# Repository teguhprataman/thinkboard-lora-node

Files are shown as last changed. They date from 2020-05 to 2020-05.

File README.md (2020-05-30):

# ThinkBoard LoRa Node V1

<p align="center">
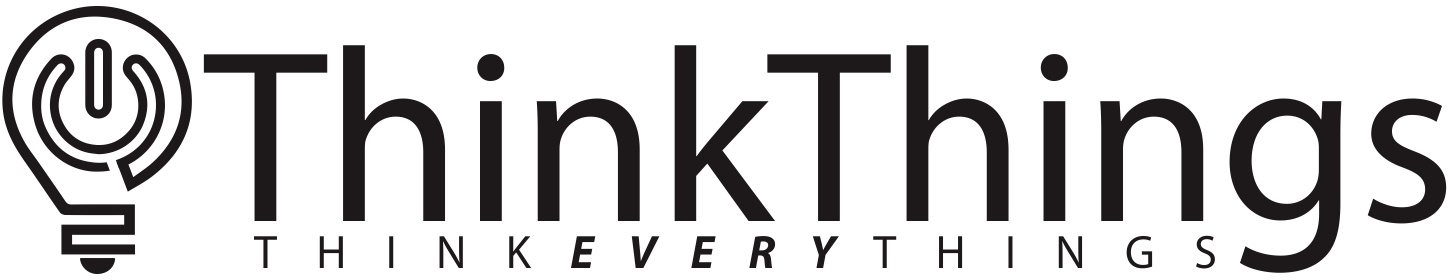
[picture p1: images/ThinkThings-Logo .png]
  
</p>

<br>

<p align="center">
  <br>
  <br>
  <b>Official Development Board For ThinkThings.id</b>
  <br> 
</p>

<p align="center"> 
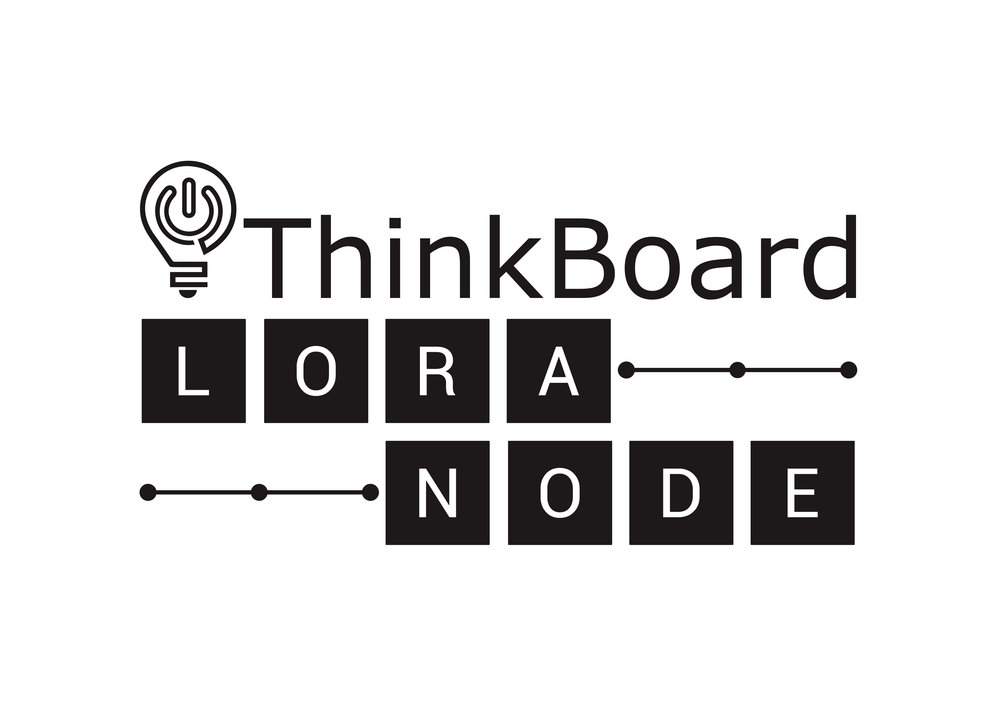
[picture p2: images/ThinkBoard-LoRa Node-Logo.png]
  
</p>

Daftar Isi
=================

<!--ts-->
   * [Daftar Isi](#daftar-isi)
   * [Deskripsi](#deskripsi)
   * [Spesifikasi](#spesifikasi)
   * [Pinout Diagram](#pinout-diagram)
   * [Bill Of Materials](#boms)
   * [Desain](#desain)
   * [Example](#example)
   * [Galeri](#galeri)
   * [Informasi](#informasi)
   * [Lisensi](#lisensi)
<!--te-->

## Deskripsi 
ThinkBoard LoRa Node V1 merupakan development board berbasis mikrokontroler ESP32 yang dilengkapi dengan modul radio HopeRF LoRa RFM95W 915MHz, sensor BME280 dan RGB LED WS2812 yang terintegrasi. Development board ini dirancang untuk mendukung segala kebutuhan pengguna dalam proyek Internet of Things, dengan tersedianya berbagai konektivitas seperti Bluetooth Low Energy, Wi-Fi, dan LoRa membuat development board ini sangat fleksibel untuk digunakan pada berbagai jaringan.

## Spesifikasi
**•	MCU :** ESP32 WROOM Dual – Core 4MB SPI Flash

**•	Dimensions :** 62mm x 38mm

**•	Headers :** 1x15 Pin & 1x17 Pin with 2.54mm pitch and castellated holes

**•	GPIO :** 26 pin GPIO @3V3 Logic Level: 2 x UART, 2 x SPI, 1 x I2C, 16 x 12 bits ADC, 2 x 8 bits DAC, 10 x Touch Capacitive, 16 x PWM Output Channels

**•	USB to UART :** Silicon Labs CP2104 USB – to – UART Bridge Controller

**•	Connectivity :** LoRa RFM95W 915MHz, Wi-Fi, Bluetooth

**•	Built-in Sensor :** BME280 digital humidity, pressure, and temperature sensor @0x76 address

**•	Built-in LED :** 3 x single color indicator LED, 1 x single color built-in LED attached to GPIO2, 1 x RGB LED WS2812 attached to GPIO33

**•	Power :** AP2112K 3.3V LDO 600mA regulator, USB or battery operated Vin : 6.5V max / 5V typ. / 4.2V min

**•	Battery Charger :** MCP73831 Single Cell Li-Ion, Li-Po battery charger

**•	Connector :** USB Micro B, U.FL antenna connector

## Pinout Diagram


***Catatan :** GPIO 34-39 hanya dapat digunakan sebagai input

## BOMs
No | Designator                        | Item/Value    | Footprint     | Quantity
-- | --------------------------------- | ------------- | ------------- | -------------
1  |  C1, C2, C4, C7, C8, C11, C12, C13| 1µF           | Ceramic 0603  | 8             |
2  |  C6                               | 4.7µF         | Ceramic 0603  | 1             |
3  |  C3, C5                           | 10µF          | Ceramic 0603  | 2             |
4  |  C9, C10                          | 4.7µF         | Ceramic 0805  | 2             |
5  |  C6                               | 4.7µF         | Ceramic 0603  | 1             |
6  |  R4, R5, R7, R8, R9, R10          | 10KΩ          |   1/16W 0603  | 6             |
7  |  R2                               | 100KΩ         |   1/16W 0603  | 1             |
8  |  R3                               | 4K7Ω          |   1/16W 0603  | 1             |
9  |  R6                               | 1KΩ           |2X4 ARRAY 0804 | 1             |
10 |  D1                               | 1N5822        |     DO214     | 1             |
11 |  D2                               | LED YELLOW    |     0603      | 1             |
12 |  D3                               | LED BLUE      |     0603      | 1             |
13 |  D4                               | LED GREEN     |     0603      | 1             |
14 |  D5                               | LED RED       |     0603      | 1             |
15 |  D2                               | LED YELLOW    |     0603      | 1             |
16 |  LED                              | WS2812B       |     5050      | 1             |
17 |  D2                               | LED YELLOW    |     0603      | 1             |
18 |  IC1                              | SI2301        |    SOT-23     | 1             |
19 |  IC2                              | AP2112K       |    SOT-25     | 1             |
20 |  IC3                              | MCP73831      |   SOT-23-5    | 1             |
21 |  U1                               | ESP32 WROOM   |   WROOM-32    | 1             |
22 |  U2                               | CP2104        |    QFN-24     | 1             |
23 |  U3                               | BME280        |  8 Pin - LGA  | 1             |
24 |  U4                               | RFM95W        |   8 x 2 Pin   | 1             |
25 |  Q1, Q2                           | MMBT3904      |    SOT-23     | 2             |
26 |  S1                               | Tactile Switch|     5 Pin     | 1             |
27 |  SW1                              | DIP Switch    |     2 Pin     | 1             |
28 |  SW1                              | DIP Switch    |     2 Pin     | 1             |
29 |  J1                               | PH Connector  |   2 Pin SMD   | 1             |
30 |  J2                               | USB Micro B   |      SMD      | 1             |
31 |  P1                               | Header 1x15   |  2.54mm Pitch | 1             |
32 |  P2                               | Header 1x17   |  2.54mm Pitch | 1             |
33 |                                   | U.FL Connector|      SMT      | 1             |

## Desain
ThinkBoard LoRa Node V1 merupakan hardware open-source yang di desain menggunakan software Altium Designer 20.1, namun terdapat juga file yang dapat dibuka menggunakan software freeware CircuitMaker.

Silakan gunakan design hardware ini dengan bijak.

File PCB Altium Designer, silakan lihat [Altium Designer](https://github.com/teguhprataman/thinkboard/tree/master/desain/Altium-Designer) 

File PCB CircuitMaker, silakan lihat [CircuitMaker](https://circuitmaker.com/Projects/Details/TeguhPratama/ThinkBoard-LoRa-Node-V1-CircuitMaker/embeded)

## Example

ThinkBoard LoRa Node V1 dapat diprogram menggunakan ArduinoIDE, dengan memilih ESP32 Dev Module pada bagian board di ArduinoIDE.

Lihat [example](https://github.com/teguhprataman/thinkboard/tree/master/example) untuk contoh program

Adapun library depedency untuk example diatas :

**• BME280** https://github.com/adafruit/Adafruit_BME280_Library

**• NeoPixel WS2812B** https://github.com/adafruit/Adafruit_NeoPixel

**• LoRa P2P** https://github.com/sandeepmistry/arduino-LoRa

**• LoRaWAN-Node** https://github.com/BeelanMX/Beelan-LoRaWAN

## Galeri
Lihat [galeri](https://github.com/teguhprataman/thinkboard/tree/master/images) untuk melihat gambar dari board ThinkBoard LoRa Node V1

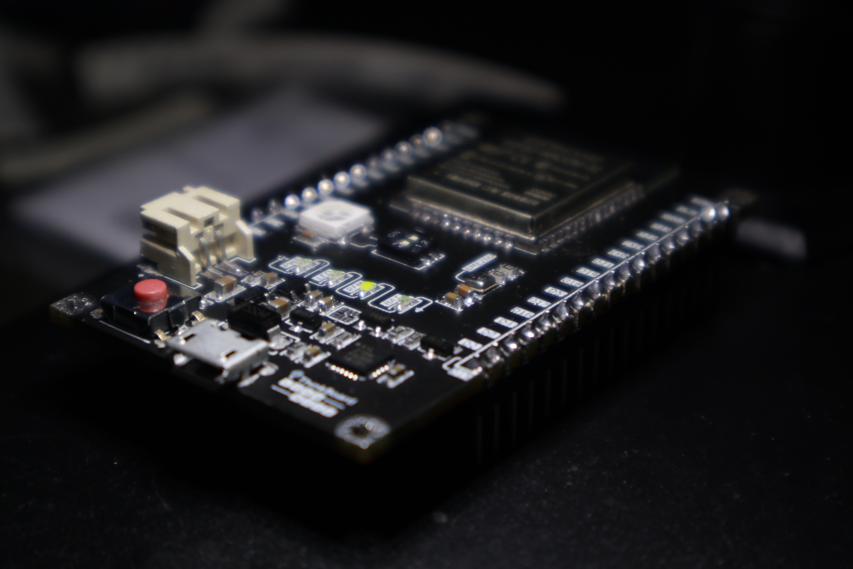
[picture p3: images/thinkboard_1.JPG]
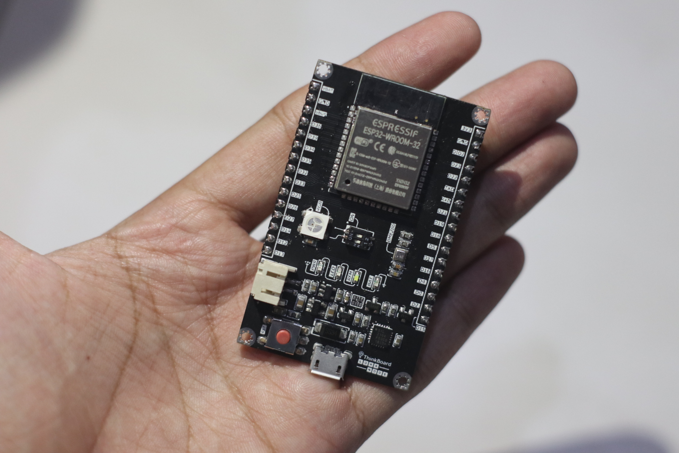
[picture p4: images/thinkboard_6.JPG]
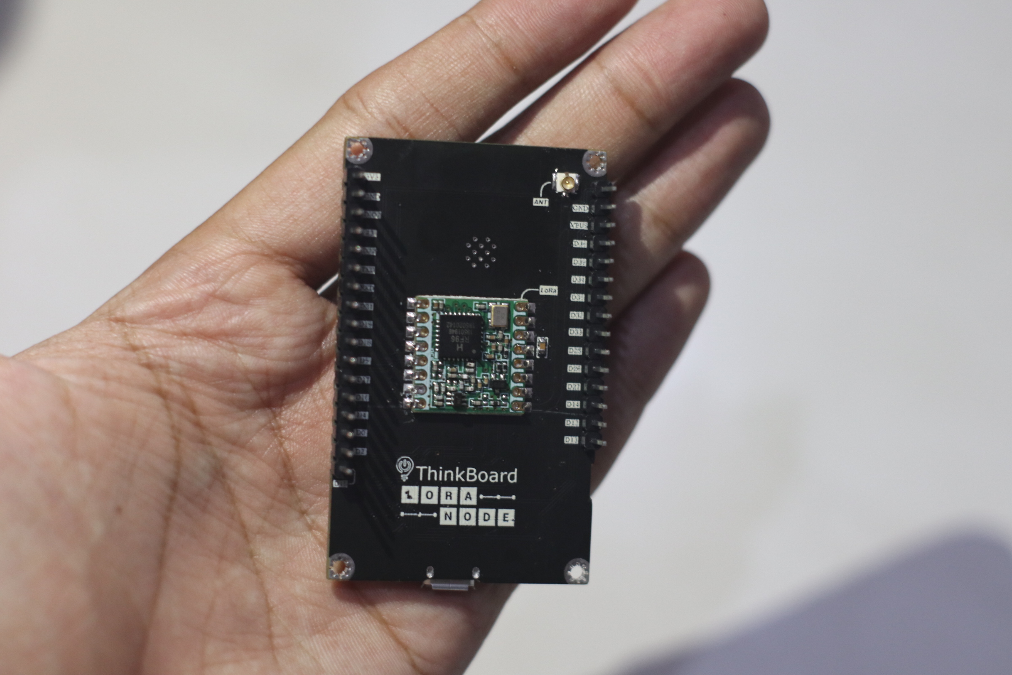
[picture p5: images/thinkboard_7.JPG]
   

## Informasi

Author : Teguh Pratama

E-mail : teguhvnkn@gmail.com

Website : thinkthings.id (offline)

## Lisensi
Desain hardware menggunakan lisensi  <a rel="license" href="http://creativecommons.org/licenses/by-nc-sa/4.0/">Creative Commons Attribution-NonCommercial-ShareAlike 4.0 International License</a>.

Software menggunakan lisensi <a rel="license" href="https://www.gnu.org/licenses/lgpl-3.0.txt">GNU Lesser General Public License Version 3</a>.

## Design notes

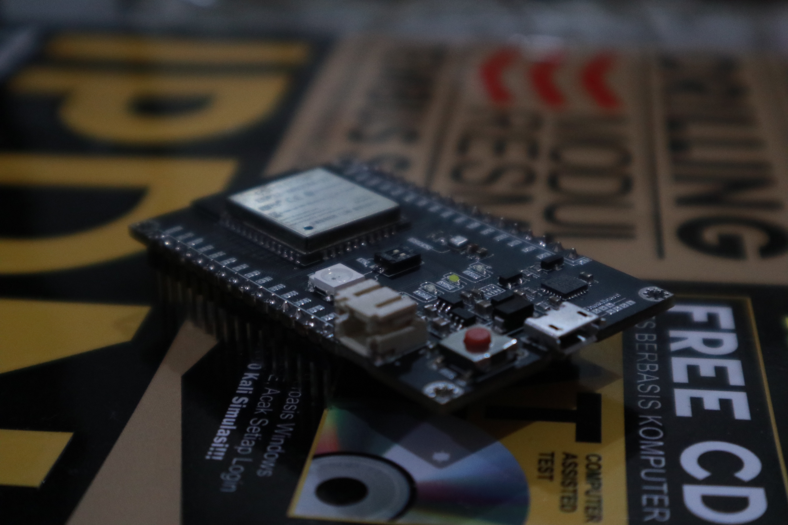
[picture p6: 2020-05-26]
images/thinkboard_2.JPG

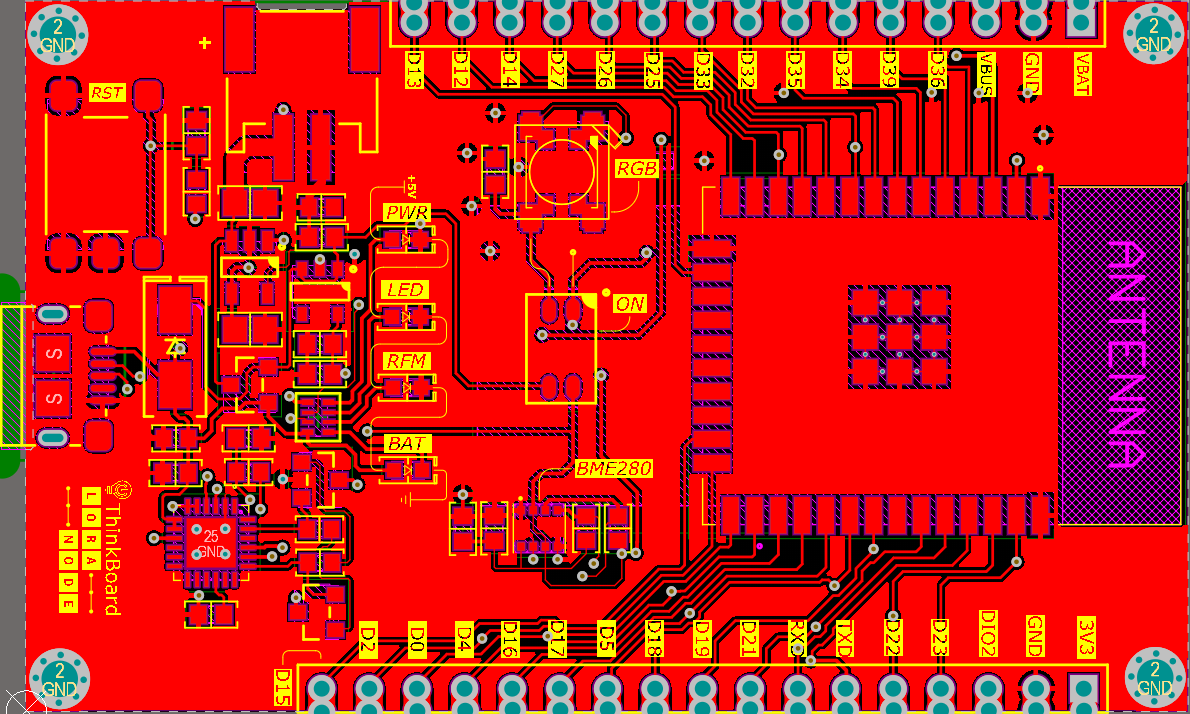
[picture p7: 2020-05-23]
images/top-layer.PNG

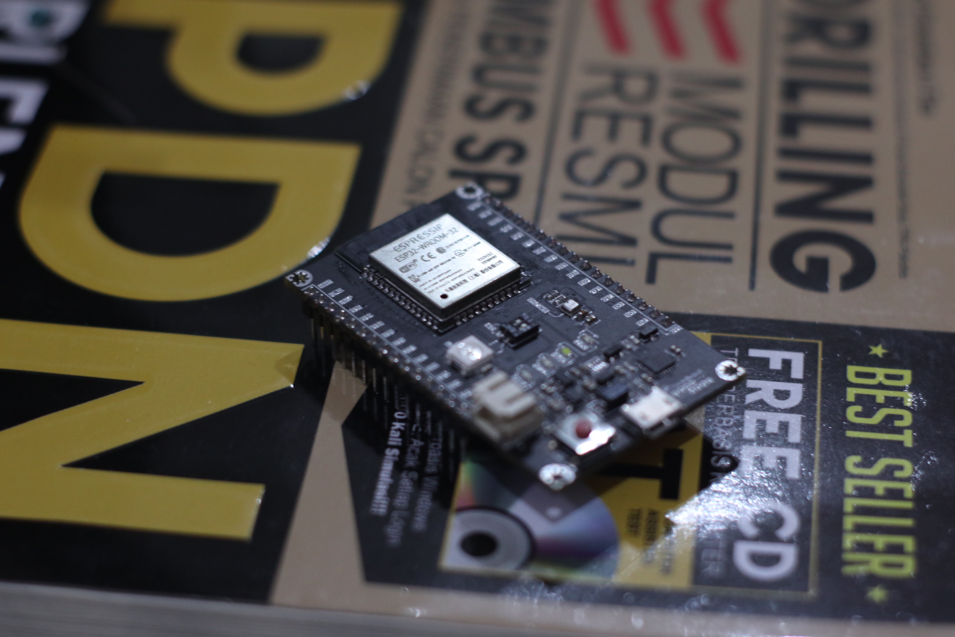
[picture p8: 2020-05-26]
images/thinkboard_3.JPG

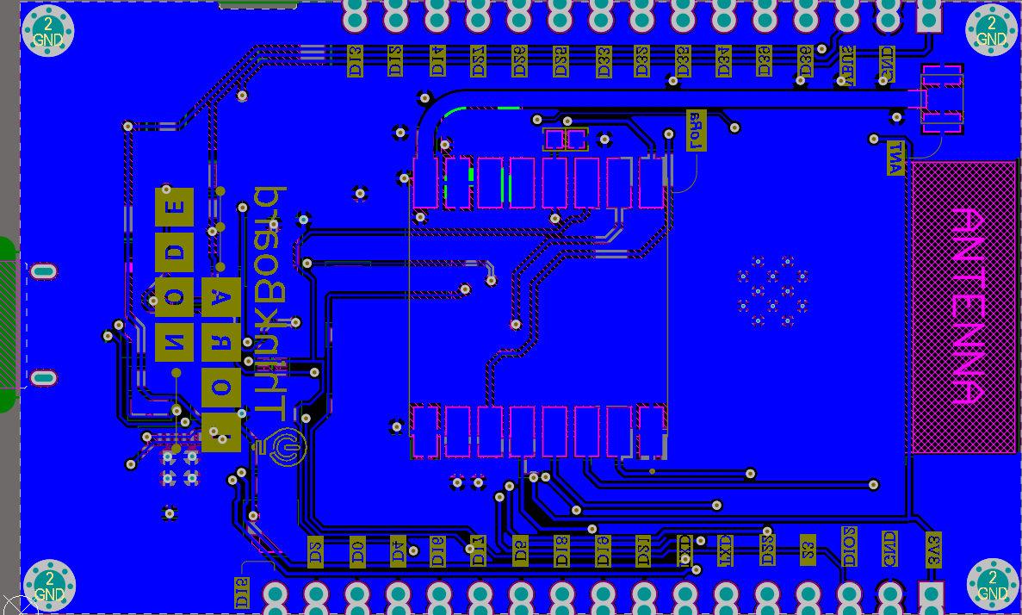
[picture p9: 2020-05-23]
images/bottom-layer.PNG

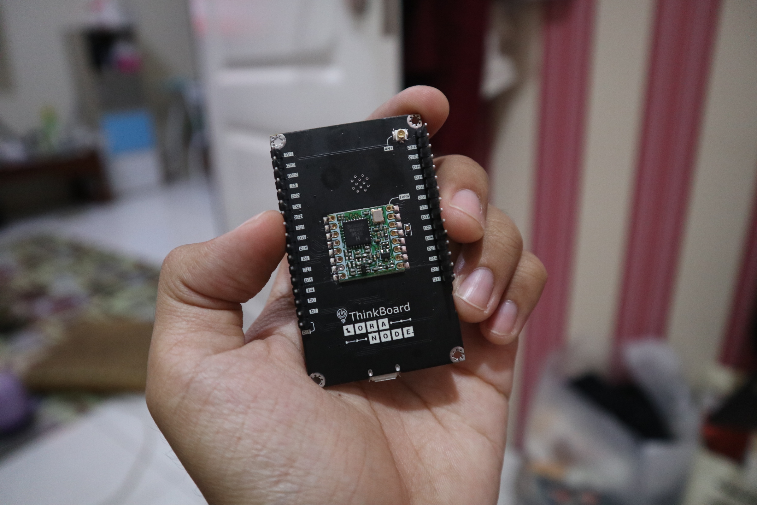
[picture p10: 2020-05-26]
images/thinkboard_4.JPG

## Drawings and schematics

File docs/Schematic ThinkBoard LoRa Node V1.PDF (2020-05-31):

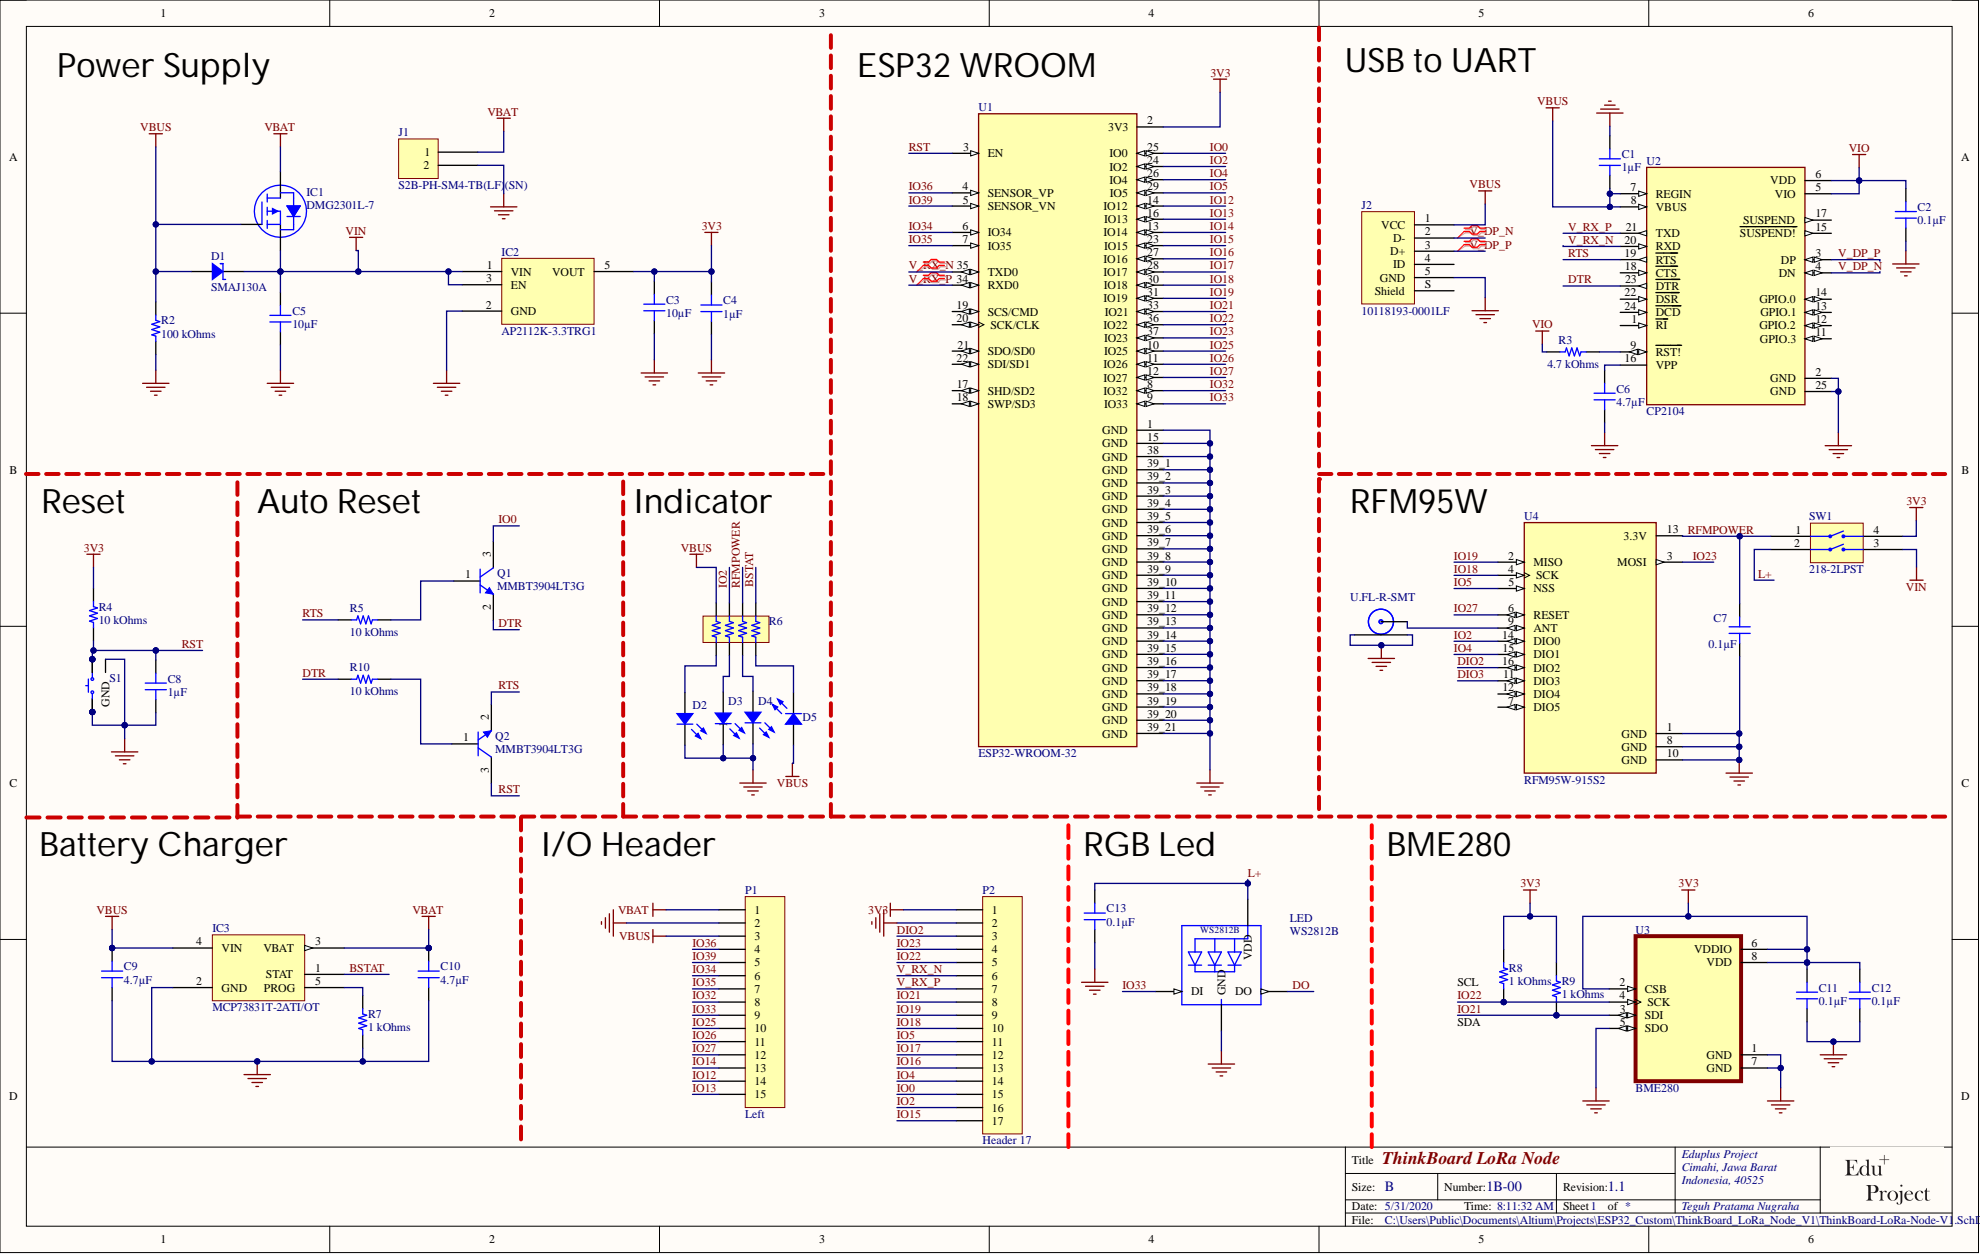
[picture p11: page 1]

C:\Users\Public\Documents\Altium\Projects\ESP32_Custom\ThinkBoard_LoRa_Node_V1\ThinkBoard-LoRa-Node-V1.SchDoc

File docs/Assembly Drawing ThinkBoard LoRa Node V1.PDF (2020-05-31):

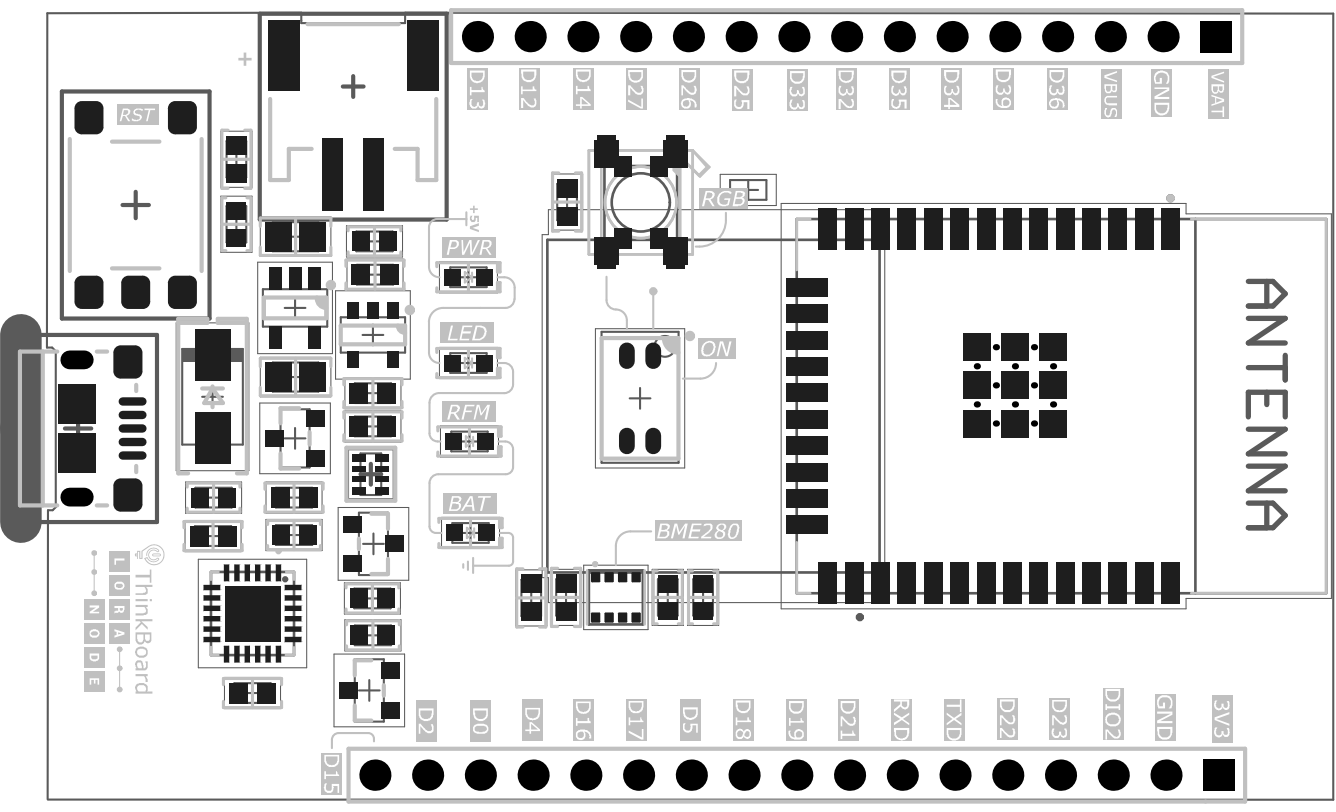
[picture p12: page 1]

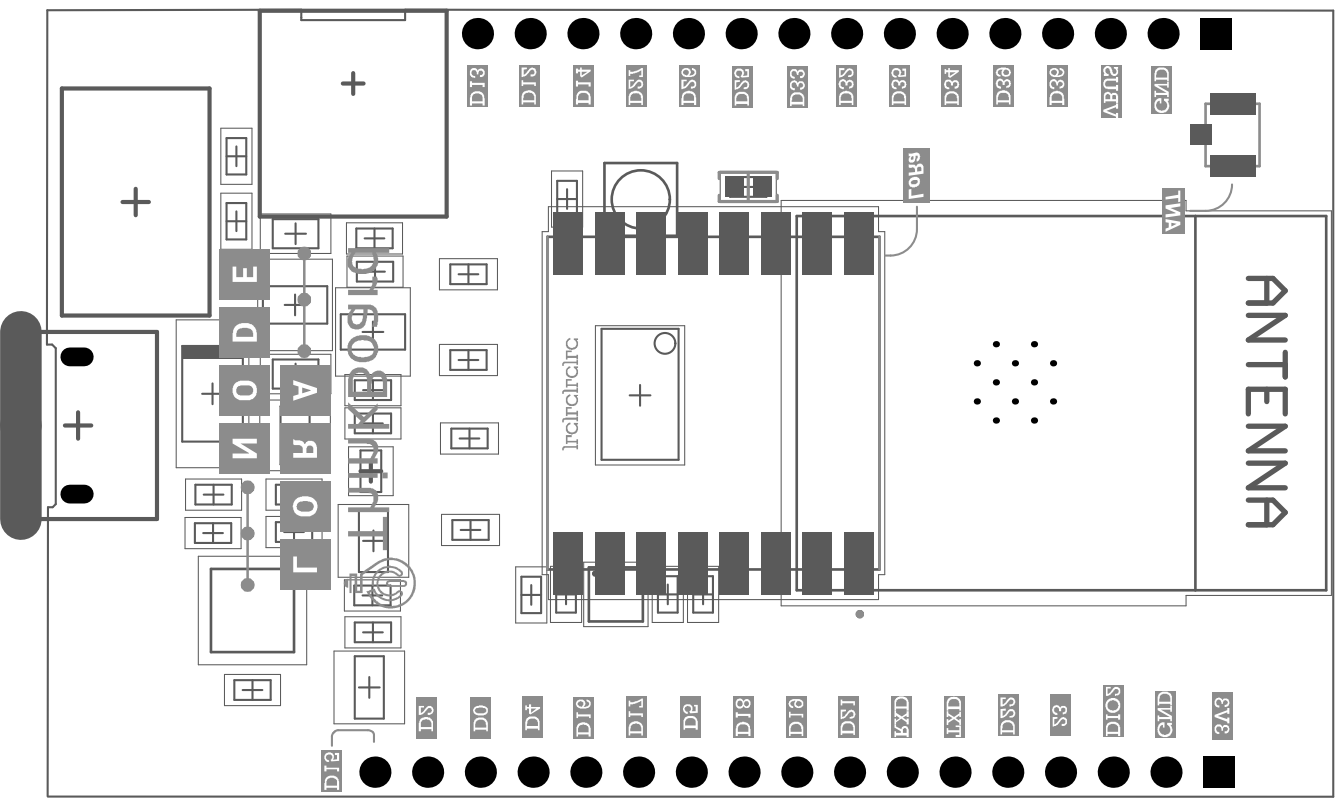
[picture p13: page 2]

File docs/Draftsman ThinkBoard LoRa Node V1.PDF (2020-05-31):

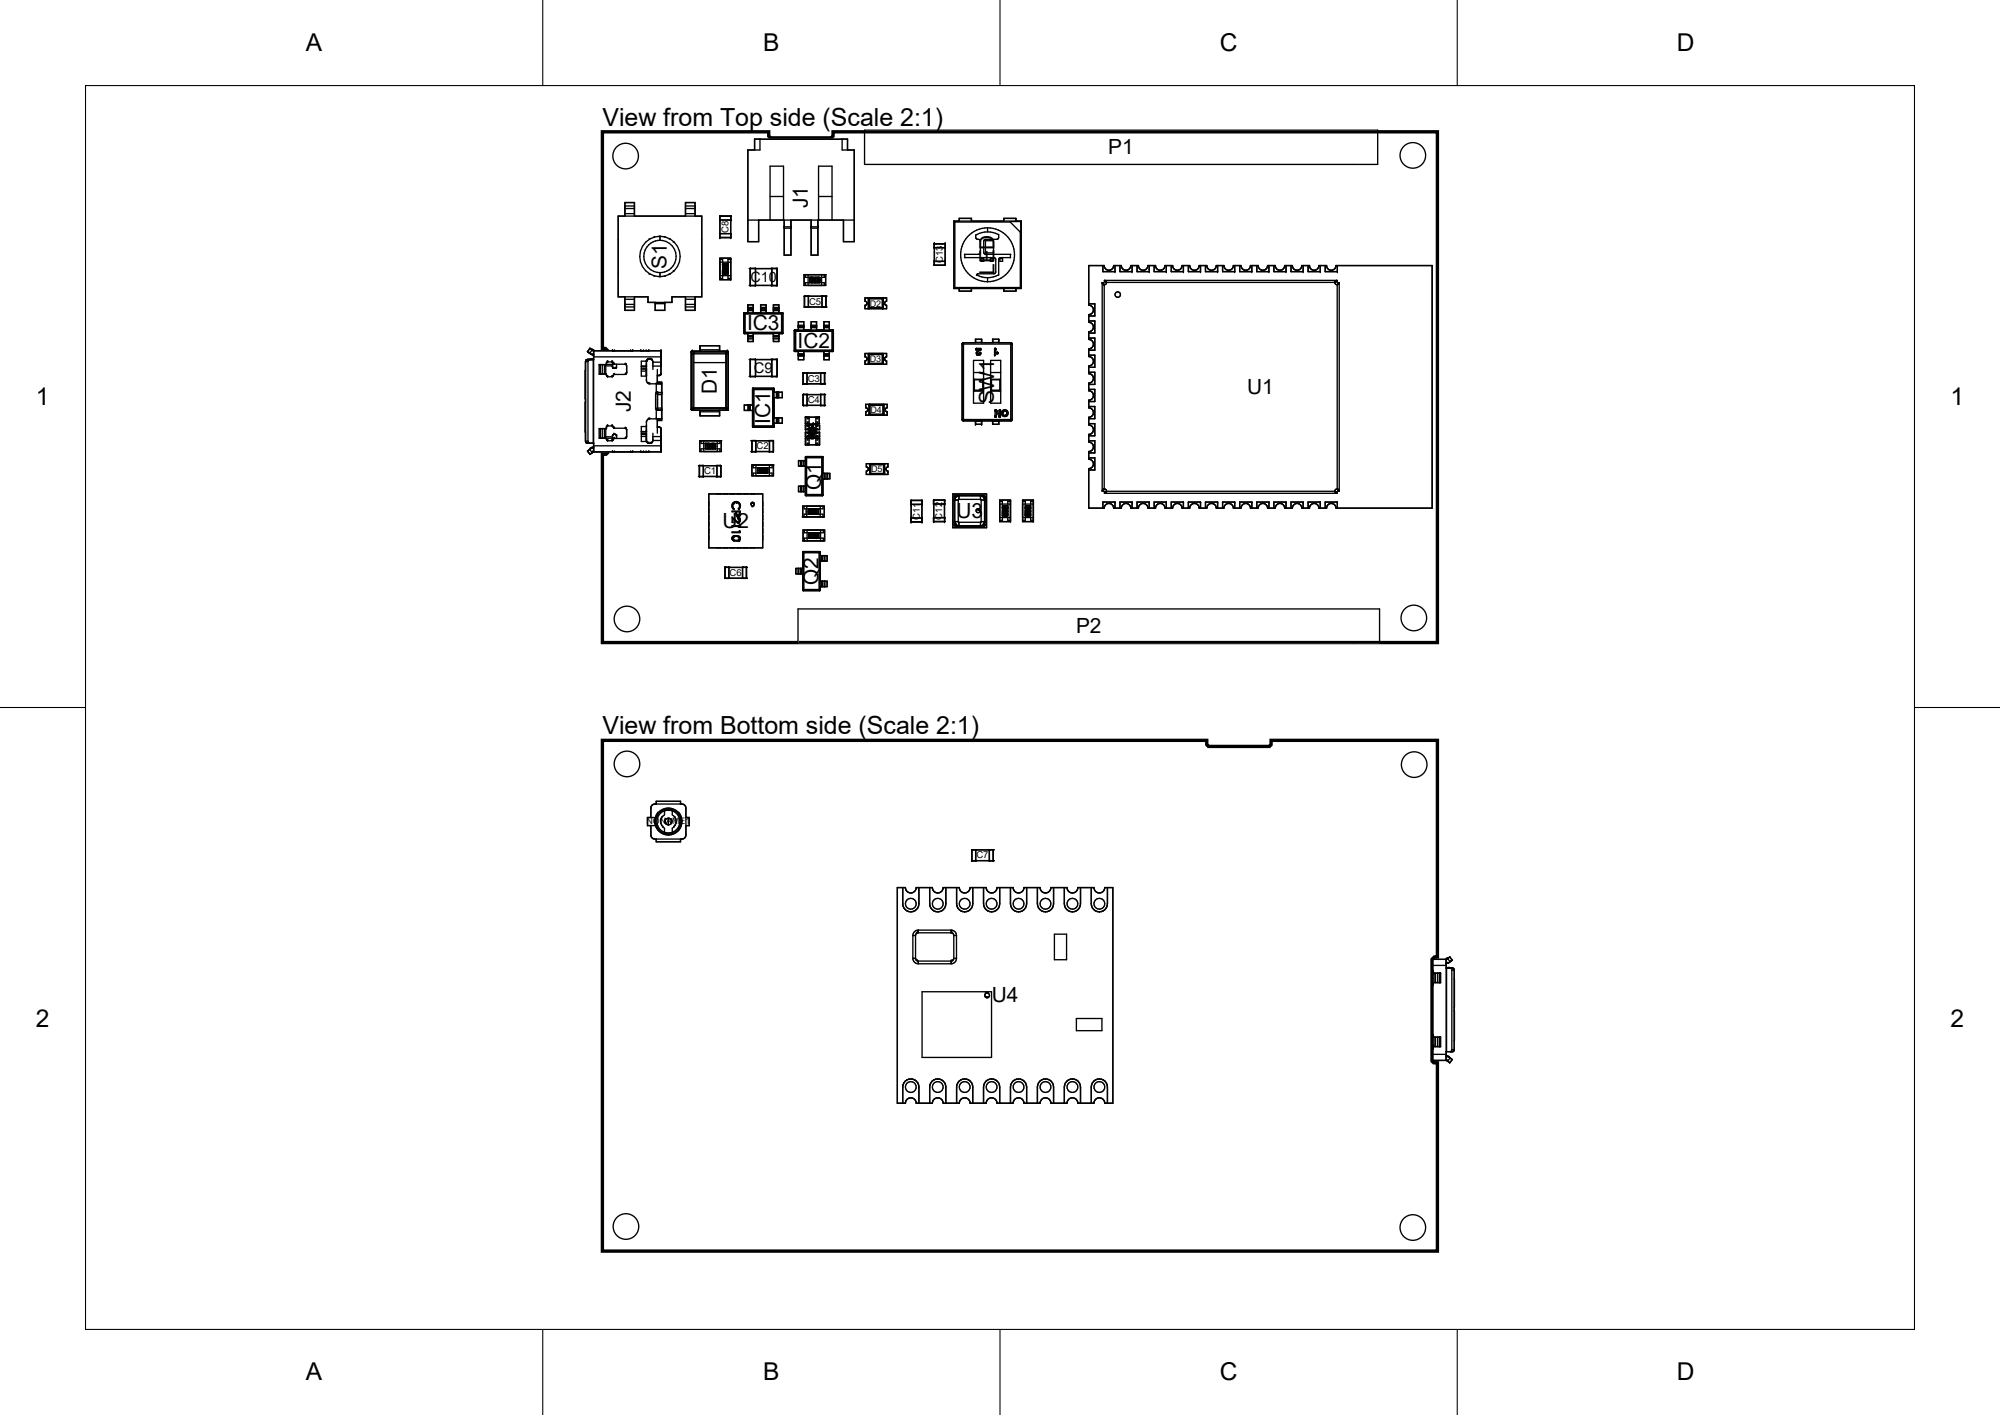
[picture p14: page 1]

View from Top side (Scale 2:1)

View from Bottom side (Scale 2:1)

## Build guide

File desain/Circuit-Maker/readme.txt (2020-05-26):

https://circuitmaker.com/Projects/Details/TeguhPratama/ThinkBoard-LoRa-Node-V1-CircuitMaker/embeded

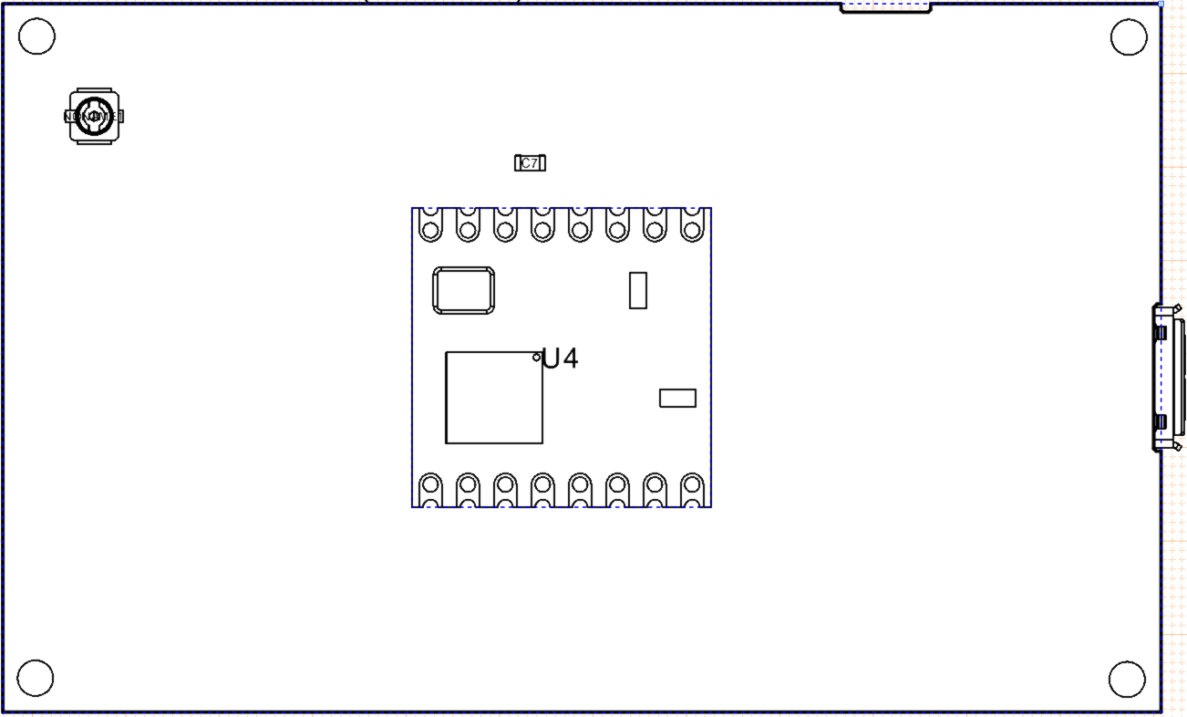
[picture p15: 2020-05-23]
images/board-assembly-bottom-layer.PNG

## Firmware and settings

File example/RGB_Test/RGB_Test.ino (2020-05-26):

// A basic everyday NeoPixel strip test program.

// NEOPIXEL BEST PRACTICES for most reliable operation:
// - Add 1000 uF CAPACITOR between NeoPixel strip's + and - connections.
// - MINIMIZE WIRING LENGTH between microcontroller board and first pixel.
// - NeoPixel strip's DATA-IN should pass through a 300-500 OHM RESISTOR.
// - AVOID connecting NeoPixels on a LIVE CIRCUIT. If you must, ALWAYS
//   connect GROUND (-) first, then +, then data.
// - When using a 3.3V microcontroller with a 5V-powered NeoPixel strip,
//   a LOGIC-LEVEL CONVERTER on the data line is STRONGLY RECOMMENDED.
// (Skipping these may work OK on your workbench but can fail in the field)

#include <Adafruit_NeoPixel.h>
#ifdef __AVR__
 #include <avr/power.h> // Required for 16 MHz Adafruit Trinket
#endif

// Which pin on the Arduino is connected to the NeoPixels?
// On a Trinket or Gemma we suggest changing this to 1:
#define LED_PIN    33

// How many NeoPixels are attached to the Arduino?
#define LED_COUNT 1

// Declare our NeoPixel strip object:
Adafruit_NeoPixel strip(LED_COUNT, LED_PIN, NEO_GRB + NEO_KHZ800);
// Argument 1 = Number of pixels in NeoPixel strip
// Argument 2 = Arduino pin number (most are valid)
// Argument 3 = Pixel type flags, add together as needed:
//   NEO_KHZ800  800 KHz bitstream (most NeoPixel products w/WS2812 LEDs)
//   NEO_KHZ400  400 KHz (classic 'v1' (not v2) FLORA pixels, WS2811 drivers)
//   NEO_GRB     Pixels are wired for GRB bitstream (most NeoPixel products)
//   NEO_RGB     Pixels are wired for RGB bitstream (v1 FLORA pixels, not v2)
//   NEO_RGBW    Pixels are wired for RGBW bitstream (NeoPixel RGBW products)


// setup() function -- runs once at startup --------------------------------

void setup() {
  // These lines are specifically to support the Adafruit Trinket 5V 16 MHz.
  // Any other board, you can remove this part (but no harm leaving it):
#if defined(__AVR_ATtiny85__) && (F_CPU == 16000000)
  clock_prescale_set(clock_div_1);
#endif
  // END of Trinket-specific code.

  strip.begin();           // INITIALIZE NeoPixel strip object (REQUIRED)
  strip.show();            // Turn OFF all pixels ASAP
  strip.setBrightness(50); // Set BRIGHTNESS to about 1/5 (max = 255)
}


// loop() function -- runs repeatedly as long as board is on ---------------

void loop() {
  // Fill along the length of the strip in various colors...
  colorWipe(strip.Color(255,   0,   0), 50); // Red
  colorWipe(strip.Color(  0, 255,   0), 50); // Green
  colorWipe(strip.Color(  0,   0, 255), 50); // Blue

  // Do a theater marquee effect in various colors...
  theaterChase(strip.Color(127, 127, 127), 50); // White, half brightness
  theaterChase(strip.Color(127,   0,   0), 50); // Red, half brightness
  theaterChase(strip.Color(  0,   0, 127), 50); // Blue, half brightness

  rainbow(10);             // Flowing rainbow cycle along the whole strip
  theaterChaseRainbow(50); // Rainbow-enhanced theaterChase variant
}


// Some functions of our own for creating animated effects -----------------

// Fill strip pixels one after another with a color. Strip is NOT cleared
// first; anything there will be covered pixel by pixel. Pass in color
// (as a single 'packed' 32-bit value, which you can get by calling
// strip.Color(red, green, blue) as shown in the loop() function above),
// and a delay time (in milliseconds) between pixels.
void colorWipe(uint32_t color, int wait) {
  for(int i=0; i<strip.numPixels(); i++) { // For each pixel in strip...
    strip.setPixelColor(i, color);         //  Set pixel's color (in RAM)
    strip.show();                          //  Update strip to match
    delay(wait);                           //  Pause for a moment
  }
}

// Theater-marquee-style chasing lights. Pass in a color (32-bit value,
// a la strip.Color(r,g,b) as mentioned above), and a delay time (in ms)
// between frames.
void theaterChase(uint32_t color, int wait) {
  for(int a=0; a<10; a++) {  // Repeat 10 times...
    for(int b=0; b<3; b++) { //  'b' counts from 0 to 2...
      strip.clear();         //   Set all pixels in RAM to 0 (off)
      // 'c' counts up from 'b' to end of strip in steps of 3...
      for(int c=b; c<strip.numPixels(); c += 3) {
        strip.setPixelColor(c, color); // Set pixel 'c' to value 'color'
      }
      strip.show(); // Update strip with new contents
      delay(wait);  // Pause for a moment
    }
  }
}

// Rainbow cycle along whole strip. Pass delay time (in ms) between frames.
void rainbow(int wait) {
  // Hue of first pixel runs 5 complete loops through the color wheel.
  // Color wheel has a range of 65536 but it's OK if we roll over, so
  // just count from 0 to 5*65536. Adding 256 to firstPixelHue each time
  // means we'll make 5*65536/256 = 1280 passes through this outer loop:
  for(long firstPixelHue = 0; firstPixelHue < 5*65536; firstPixelHue += 256) {
    for(int i=0; i<strip.numPixels(); i++) { // For each pixel in strip...
      // Offset pixel hue by an amount to make one full revolution of the
      // color wheel (range of 65536) along the length of the strip
      // (strip.numPixels() steps):
      int pixelHue = firstPixelHue + (i * 65536L / strip.numPixels());
      // strip.ColorHSV() can take 1 or 3 arguments: a hue (0 to 65535) or
      // optionally add saturation and value (brightness) (each 0 to 255).
      // Here we're using just the single-argument hue variant. The result
      // is passed through strip.gamma32() to provide 'truer' colors
      // before assigning to each pixel:
      strip.setPixelColor(i, strip.gamma32(strip.ColorHSV(pixelHue)));
    }
    strip.show(); // Update strip with new contents
    delay(wait);  // Pause for a moment
  }
}

// Rainbow-enhanced theater marquee. Pass delay time (in ms) between frames.
void theaterChaseRainbow(int wait) {
  int firstPixelHue = 0;     // First pixel starts at red (hue 0)
  for(int a=0; a<30; a++) {  // Repeat 30 times...
    for(int b=0; b<3; b++) { //  'b' counts from 0 to 2...
      strip.clear();         //   Set all pixels in RAM to 0 (off)
      // 'c' counts up from 'b' to end of strip in increments of 3...
      for(int c=b; c<strip.numPixels(); c += 3) {
        // hue of pixel 'c' is offset by an amount to make one full
        // revolution of the color wheel (range 65536) along the length
        // of the strip (strip.numPixels() steps):
        int      hue   = firstPixelHue + c * 65536L / strip.numPixels();
        uint32_t color = strip.gamma32(strip.ColorHSV(hue)); // hue -> RGB
        strip.setPixelColor(c, color); // Set pixel 'c' to value 'color'
      }
      strip.show();                // Update strip with new contents
      delay(wait);                 // Pause for a moment
      firstPixelHue += 65536 / 90; // One cycle of color wheel over 90 frames
    }
  }
}

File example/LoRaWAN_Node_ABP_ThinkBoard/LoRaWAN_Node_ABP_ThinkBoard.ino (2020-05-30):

#include <lorawan.h>
#include <Wire.h>
#include <Adafruit_Sensor.h>
#include <Adafruit_BME280.h>
#include <Adafruit_NeoPixel.h>
#include <ArduinoJson.h>

#define BME_ADDR 0x76 //Address BME280
#define SEALEVELPRESSURE_HPA (1013.25)
#define PIN 33 // Pin NeoPixel di ThinkBoard LoRa Node
#define NUMPIXELS 1 // Jumlah led RGB


//ABP Credentials 
const char *devAddr = "260415A0"; //Sesuaikan dengan Device Address di TTN
const char *nwkSKey = "9D582639715DD1093B5A18A3BBCB0F14"; //Sesuaikan dengan Network Session Key di TTN
const char *appSKey = "54276A8182DA0ADD0209724FE5A8BEF0"; //Sesuaikan dengan Apps Key di TTN

// Delay
const unsigned long interval = 30000;    // Sesuaikan dengan uplink fair usage di TTN
unsigned long previousMillis = 0;  

// Variabel untuk BME280
int suhu;     
int lembab;
int tekanan;

char myStr[255];
char outStr[255];
byte recvStatus = 0;

// Pin LoRa RFM95W di ThinkBoard LoRa Node
const sRFM_pins RFM_pins = {
  .CS = 5, //NSS
  .RST = 27, //RST
  .DIO0 = 2, //DIO0
  .DIO1 = 4 //DIO1
};


Adafruit_BME280 bme;
Adafruit_NeoPixel pixels(NUMPIXELS, PIN, NEO_GRB + NEO_KHZ800);

void setup() {
  // Setup loraid access
  Serial.begin(115200);
  pixels.begin();
  pixels.show();
  pixels.setBrightness(50);
  
  Serial.println("Set BME");
  bool status;
  status = bme.begin(BME_ADDR);
  if (!status) {
    Serial.println("BME280 tidak ditemukan!");
    while (1);
  }
  Serial.println("BME OK!");
  colorWipe(pixels.Color(209,0,0), 500);
  delay(2000);
  
  Serial.println("Set LoRa!");
  if(!lora.init()){
    Serial.println("RFM95 tidak terdeteksi, periksa sambungan!");
    delay(5000);
    return;
  }
  colorWipe(pixels.Color(16,6,209), 500); 
  Serial.println("LoRa OK!");
  delay(2000);
  // Set LoRaWAN Class change CLASS_A or CLASS_C
  lora.setDeviceClass(CLASS_A);

  // Set Data Rate
  lora.setDataRate(SF7BW125);

  // set channel to random
  lora.setChannel(MULTI);
  
  // Put ABP Key and DevAddress here
  lora.setNwkSKey(nwkSKey);
  lora.setAppSKey(appSKey);
  lora.setDevAddr(devAddr);
}

void loop() {
  theaterChase(pixels.Color(127, 127, 127), 250); // 
  measure(); 
  if(millis() - previousMillis > interval) {
    previousMillis = millis();
    colorWipe(pixels.Color(48,   240,   0), 500);
    encodeJson(); 
    sendLora();
  }
}

void measure(){
  suhu = bme.readTemperature();
  tekanan = (bme.readPressure() / 100.0F);
  lembab = bme.readHumidity();
}

void encodeJson(){
  StaticJsonDocument<255> doc;
  doc["suhu"] = suhu;
  doc["kelembaban"] = lembab;
  doc["tekanan"] = tekanan;
  serializeJson(doc,myStr);
}

void sendLora(){
  Serial.print("Sending: ");
  Serial.println(myStr);   
  lora.sendUplink(myStr, strlen(myStr), 0);

  recvStatus = lora.readData(outStr);
  if(recvStatus) {
    Serial.println(outStr);
  }
  
  // Check Lora RX
  lora.update();  
}

void colorWipe(uint32_t color, int wait) {
  for(int i=0; i<pixels.numPixels(); i++) { 
    pixels.setPixelColor(i, color);         
    pixels.show();                         
    delay(wait);                           
  }
}

void theaterChase(uint32_t color, int wait) {
  for(int a=0; a<10; a++) {  // Repeat 10 times...
    for(int b=0; b<3; b++) { //  'b' counts from 0 to 2...
      pixels.clear();         //   Set all pixels in RAM to 0 (off)
      // 'c' counts up from 'b' to end of strip in steps of 3...
      for(int c=b; c<pixels.numPixels(); c += 3) {
        pixels.setPixelColor(c, color); // Set pixel 'c' to value 'color'
      }
      pixels.show(); // Update strip with new contents
      delay(wait);  // Pause for a moment
    }
  }
}

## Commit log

2020-05-26 Update link pcb documents
2020-05-26 Update link circuit maker
2020-05-27 update lisensi di README.md
